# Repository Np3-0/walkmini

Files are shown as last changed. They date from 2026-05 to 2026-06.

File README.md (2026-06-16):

# Walk-Mini
A customizable, portable music player created for Hack Club: Fallout.

## About Walk-Mini
Music is one of the only genres that can connect people who believe in different topics, live in different areas, and who even speak different languages. However, it is becoming harder to listen to it, without shelling out 10 dollars a month, or buying a vinyl (which nobody will carry around). <br> People already carry around old IPods and other technology like this, so I wanted to make my own spin on it.

## Key Features
* Fully customizable theming
  - Users can print their own cases and choose between a wide range of themes for the firmware.
* Bluetooth, Headphone Jack, and Speaker support!
* 2.4 Inch TFT display with vibrant colors!
* Unlimited Song Storage!
  - Depends on SD size.
* And More!

## How to Use
1. Put in **4 AA Batteries**.
2. It should start up automatically!
   - I would recommend taking batteries out when not in use, in order to save power.
<br>
On the main page, there are six options (characterized with icons): Restart, Pause/Resume, Skip, Songs, Shuffle, and Settings.
<br>The settings page contains Customize, Bluetooth, and Contributions.

## How to Build
1. Buy all parts listed.
2. Print the case bottom, top, and battery cover (I would recommend either TPU or PLA).
3. Once the PCB arrives, solder all components onto it, following the PCB layout.
4. Connect a USB-C cable to the USB-header from your computer, and use the Arduino editor to flash the firmware onto the ESP.
5. Put the assembled PCB inside of the case, and enjoy!
6. Make sure you have songs loaded into the SD Card. 

## Photos
### **PCB**:<br> image of pcb in kicad
### **Zine:** <br> zine
### **CAD: (Link [here](https://cad.onshape.com/documents/891581ea64ec99eaf423b0d6/w/ed4d009452ec0fea7080dfa2/e/6ade851cf838900c5ee38ccd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))** <br> cad

##

## BOM
| Part Name | Description | Quantity | Unit Price | Total Price | URL | Running Total |
| --- | --- | --- | --- | --- | --- | --- |
| ESP32-WROOM-32E-N4 | MCU | 1 | $3.22 | $3.22 | [AliExpress](https://www.aliexpress.us/item/3256806057158706.html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) | $3.43
| CP2102-GMR | USB to UART | 1 | $0.80 | $0.80 | [AliBaba](https://www.alibaba.com/product-detail/New-and-Original-CP2102-GMR-Electronic_1601731751516.html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) | $4.28
| SD-6-B | SD Card Reader | 1 | $0.58[^1] | $0.58 | [Same Sky](https://www.sameskydevices.com/product/interconnect/connectors/memory-card-connectors/sd-card-connectors/sd-6-b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) | $4.90
| 1825910-6 | 6mm Button | 6[^2] | $0.057 | 1.14 | [AliExpress](https://www.aliexpress.us/item/3256805658758223.html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) | $5.26
| PCM5102APWR | Audio Jack Controller | 1 | $1.00 | $1.00 | [AliBaba](https://www.alibaba.com/product-detail/PCM5102APWR-IC-Chip-20-TSSOP-Brand_1600511085959.html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) | $6.33 
| MAX98357AETE+T | Speaker Controller | 1 | $0.10 | $0.10 | [AliBaba](https://www.alibaba.com/product-detail/New-and-Original-MAX98357AETE-T-Electronic_1601732000471.html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) | $6.44
| SJ-3523-SMT-TR | Headphone Jack | 1 | $0.88 | $0.88 | [DigiKey](https://www.digikey.com/en/products/detail/same-sky-formerly-cui-devices/SJ-3523-SMT-TR/281297) | $7.38
| AI-4328-P-C120D-R | Speaker | 1 | $16.92 | $16.92 | [DigiKey](https://www.digikey.com/en/products/detail/pui-audio-inc/ai-4328-p-c120d-r/1738481) | $25.42
| 2477 | Battery Holder | 1 | $1.87 | $1.87 | [Digikey](https://www.digikey.com/en/products/detail/keystone-electronics/2477/303822) | $27.41
| MCP1826S-3302E/AB | LDO | 1 | $0.66 | $0.66 | [AliBaba](https://www.alibaba.com/product-detail/Electronic-Circuit-Components-MCP1826S-3302E-AB_1601731375638.html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) | $28.11
| USB4085-GF-A | USB-C Connector | 1 | $0.04 | $0.04 | [AliBaba](https://www.alibaba.com/product-detail/Hainayu-BOM-capacitor-resistance-table-quotation_1601270438701.html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) | $28.15
| 1N5819 | Schottky Diode | 1 | $0.01 | $0.01 | [AliBaba](https://www.alibaba.com/product-detail/Through-hole-Schottky-Diodes-1N5817-1N5818_1601557699434.html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) | $28.16
| SSK02-FPH-254-A14 | Display 14 Pin Connector | 1 | $0.54 | $0.54 | [DigiKey](https://www.digikey.com/en/products/detail/same-sky-formerly-cui-devices/SSK02-FPH-254-A14/28772145) | $28.74
| ILI9341 | 2.4 Inch TFT Display | 1 | $5.16 | $5.16 | [AliExpress](https://www.aliexpress.us/item/3256803732365701.html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) | $34.24
| PCB | JLCPCB for project | 5 | $1.64 | $8.20 | [JLCPCB](https://jlcpcb.com/) | $42.98
| ABS07-32.768KHZ-T | 32.768 Khz Crsytal | 1 | $0.61 | $0.61 | [Digikey](https://www.digikey.com/en/products/detail/abracon-llc/ABS07-32-768KHZ-T/1236858) | $43.63
| MBA02040C3003FC100 | 300K Ohm Resistor | 1 | $0.66 | $0.66 | [Digikey](https://www.digikey.com/en/products/detail/vishay-beyschlag-draloric-bc-components/MBA02040C3003FC100/7350347) | $44.33
| MBA02040C1002FRP00 | 10K Ohm Resistor | 10 | $0.095 | $0.95 | [Digikey](https://www.digikey.com/en/products/detail/vishay-beyschlag-draloric-bc-components/MBA02040C1002FRP00/336349) | $45.34
| MBA02040Z0000ZCT00 | 0 Ohm Resistor | 2 | $0.14 | $0.28 | [Digikey](https://www.digikey.com/en/products/detail/vishay-beyschlag-draloric-bc-components/MBA02040Z0000ZCT00/5066485) | $45.64
| MBA02040C5104FC100 | 5M Ohm Resistor | 1 | $0.39 | $0.39 | [Digikey](https://www.digikey.com/en/products/detail/vishay-beyschlag-draloric-bc-components/MBA02040C5104FC100/5059352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) | $46.06
| MBA02040C4707JC100 | 470 Ohm Resistor | 2 | $0.11 | $0.22 | [Digikey](https://www.digikey.com/en/products/detail/vishay-beyschlag-draloric-bc-components/MBA02040C4700FRP00/333739) | $46.29
| MBA02040C5101FRP00 | 5.1K Ohm Resistor | 2 | $0.11 | $0.22 | [Digikey](https://www.digikey.com/en/products/detail/vishay-beyschlag-draloric-bc-components/MBA02040C5101FRP00/333758) | $46.52
| MBA02040C2209FCT00 | 22 Ohm Resistor | 2 | $0.21 | $0.42 | [Digikey](https://www.digikey.com/en/products/detail/vishay-beyschlag-draloric-bc-components/MBA02040C2209FCT00/5062426) | $46.97
| FK14X5R0J226MR020 | 22 µF Capacitor | 2 | $0.50 | $1.00 | [Digikey](https://www.digikey.com/en/products/detail/tdk/FK14X5R0J226MR020/2815215) | $48.04
| FK14X7R2A104KN020 | 0.1 µF Capacitor | 10 | $0.253 | $2.53 | [Digikey](https://www.digikey.com/en/products/detail/tdk/FK14X7R2A104KN020/2815243) | $50.74
| FG18C0G1H120JNT06 | 12pF Capacitor | 2 | $0.22 | $0.44 | [Digikey](https://www.digikey.com/en/products/detail/tdk/FG18C0G1H120JNT06/5802787) | $51.21
| FG18X7R1A225KRT06 | 2.2 µF Capacitor | 4 | $0.32 | $1.28 | [Digikey](https://www.digikey.com/en/products/detail/tdk/FG18X7R1A225KRT06/5802874) | $52.57
| FK18X5R0J105KN020 | 1 µF Capacitor | 2 | $0.28 | $0.56 | [Digikey](https://www.digikey.com/en/products/detail/tdk/FK18X5R0J105KN020/2815325) | $53.17
| FK18X5R1A475KR020 | 4.7 µF Capacitor | 1 | $0.34 | $0.34 | [Digikey](https://www.digikey.com/en/products/detail/tdk/FK18X5R1A475KR020/2815334) | $53.53
| ECE-A1EKA100I | 10 µF Polarized Capacitor | 5 | $0.26 | $1.30 | [Digikey](https://www.digikey.com/en/products/detail/panasonic-industry/ECE-A1EKA100I/2689086) | $54.92

**Enjoy!**
---
Made with love by Np3 (nate), 17, NJ

[^1]: Price is assumed for one SD-reader. For multiple, go [here:](https://www.alibaba.com/product-detail/Brand-New-Original-CONN-SD-CARD_1601485307544.html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)
[^2]: Button comes in package of 20.

# License
Shield: [][cc-by-nc-sa]

This work is licensed under a
[Creative Commons Attribution-NonCommercial-ShareAlike 4.0 International License][cc-by-nc-sa].

[][cc-by-nc-sa]

[cc-by-nc-sa]: http://creativecommons.org/licenses/by-nc-sa/4.0/
[cc-by-nc-sa-image]: https://licensebuttons.net/l/by-nc-sa/4.0/88x31.png
[cc-by-nc-sa-shield]: https://img.shields.io/badge/License-CC%20BY--NC--SA%204.0-lightgrey.svg

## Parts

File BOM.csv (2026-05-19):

Part Name | Description | Quantity | Unit Price | Total Price | URL | Running Total
ESP32-WROOM-32E-N4 | MCU | 1 | $3.22 | $3.22 | https://www.aliexpress.us/item/3256806057158706.html | $3.43
CP2102-GMR | USB to UART | 1 | $0.80 | $0.80 | https://www.alibaba.com/product-detail/New-and-Original-CP2102-GMR-Electronic_1601731751516.html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 | $4.28
SD-6-B | SD Card Reader | 1 | $0.58 | $0.58 | https://www.sameskydevices.com/product/interconnect/connectors/memory-card-connectors/sd-card-connectors/sd-6-b | $4.90
1825910-6 | 6mm Button | 6 | $0.06 | $0.34 | https://www.aliexpress.us/item/3256805658758223.html?curPageLogUid=a4N1OIlqDFoz | $5.26
PCM5102APWR | Audio Jack Controller | 1 | $1.00 | $1.00 | https://www.alibaba.com/product-detail/New-and-Original-MAX98357AETE-T-Electronic_1601732000471.html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 | $6.33
MAX98357AETE+T | Speaker Controller | 1 | $0.10 | $0.10 | https://www.alibaba.com/product-detail/New-and-Original-MAX98357AETE-T-Electronic_1601732000471.html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 | $6.44
SJ-3523-SMT-TR | Headphone Jack | 1 | $0.88 | $0.88 | https://www.digikey.com/en/products/detail/same-sky-formerly-cui-devices/SJ-3523-SMT-TR/281297 | $7.38
AI-4328-P-C120D-R | Speaker | 1 | $16.92 | $16.92 | https://www.digikey.com/en/products/detail/pui-audio-inc/ai-4328-p-c120d-r/1738481 | $25.42
2477 | Battery Holder | 1 | $1.87 | $1.87 | https://www.digikey.com/en/products/detail/keystone-electronics/2477/303822 | $27.41
MCP1826S-3302E/AB | LDO | 1 | $0.66 | $0.66 | https://www.alibaba.com/product-detail/Electronic-Circuit-Components-MCP1826S-3302E-AB_1601731375638.html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 | $28.11
USB4085-GF-A | USB-C Connector | 1 | $0.04 | $0.04 | https://www.alibaba.com/product-detail/Hainayu-BOM-capacitor-resistance-table-quotation_1601270438701.html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 | $28.15
1N5819 | Schottky Diode | 1 | $0.01 | $0.01 | https://www.alibaba.com/product-detail/Through-hole-Schottky-Diodes-1N5817-1N5818_1601557699434.html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 | $28.16
SSK02-FPH-254-A14 | Display 14 Pin Connector | 1 | $0.54 | $0.54 | https://www.digikey.com/en/products/detail/same-sky-formerly-cui-devices/SSK02-FPH-254-A14/28772145 | $28.74
ILI9341 | 2.4 Inch TFT Display | 1 | $5.16 | $5.16 | https://www.aliexpress.us/item/3256803732365701.html?curPageLogUid=W4D3fCRCIHOw | $34.24
PCB | JLCPCB for project | 5 | $1.64 | $8.20 | https://jlcpcb.com/ | $42.98
ABS07-32.768KHZ-T | 32.768 Khz Crsytal | 1 | $0.61 | $0.61 | https://www.digikey.com/en/products/detail/abracon-llc/ABS07-32-768KHZ-T/1236858 | $43.63
MBA02040C3003FC100 | 300K Ohm Resistor | 1 | $0.66 | $0.66 | https://www.digikey.com/en/products/detail/vishay-beyschlag-draloric-bc-components/MBA02040C3003FC100/7350347 | $44.33
MBA02040C1002FRP00 | 10K Ohm Resistor | 10 | $0.10 | $0.95 | https://www.digikey.com/en/products/detail/vishay-beyschlag-draloric-bc-components/MBA02040Z0000ZCT00/5066485 | $45.34
MBA02040Z0000ZCT00 | 0 Ohm Resistor | 2 | $0.14 | $0.28 | https://www.digikey.com/en/products/detail/vishay-beyschlag-draloric-bc-components/MBA02040Z0000ZCT00/5066485 | $45.64
MBA02040C5104FC100 | 5M Ohm Resistor | 1 | $0.39 | $0.39 | https://www.digikey.com/en/products/detail/vishay-beyschlag-draloric-bc-components/MBA02040C5104FC100/5059352 | $46.06
MBA02040C4707JC100 | 470 Ohm Resistor | 2 | $0.49 | $0.98 | https://www.digikey.com/en/products/detail/vishay-beyschlag-draloric-bc-components/MBA02040C4707JC100/5059320 | $47.10
MBA02040C5101FRP00 | 5.1K Ohm Resistor | 2 | $0.11 | $0.22 | https://www.digikey.com/en/products/detail/vishay-beyschlag-draloric-bc-components/MBA02040C5101FRP00/333758 | $47.33
MBA02040C2209FCT00 | 22 Ohm Resistor | 2 | $0.21 | $0.42 | https://www.digikey.com/en/products/detail/vishay-beyschlag-draloric-bc-components/MBA02040C2209FCT00/5062426 | $47.78
FK14X5R0J226MR020 | 22 µF Capacitor | 2 | $0.50 | $1.00 | https://www.digikey.com/en/products/detail/tdk/FK14X5R0J226MR020/2815215 | $48.85
FK14X7R2A104KN020 | 0.1 µF Capacitor | 10 | $0.25 | $2.53 | https://www.digikey.com/en/products/detail/tdk/FK14X7R2A104KN020/2815243 | $51.55
FG18C0G1H120JNT06 | 12pF Capacitor | 2 | $0.22 | $0.44 | https://www.digikey.com/en/products/detail/tdk/FG18C0G1H120JNT06/5802787 | $52.02
FG18X7R1A225KRT06 | 2.2 µF Capacitor | 4 | $0.32 | $1.28 | https://www.digikey.com/en/products/detail/tdk/FG18X7R1A225KRT06/5802874 | $53.38
FK18X5R0J105KN020 | 1 µF Capacitor | 2 | $0.28 | $0.56 | https://www.digikey.com/en/products/detail/tdk/FK18X5R0J105KN020/2815325 | $53.98
FK18X5R1A475KR020 | 4.7 µF Capacitor | 1 | $0.34 | $0.34 | https://www.digikey.com/en/products/detail/tdk/FK18X5R1A475KR020/2815334 | $54.34
ECE-A1EKA100I | 10 µF Polarized Capacitor | 5 | $0.26 | $1.30 | https://www.digikey.com/en/products/detail/panasonic-industry/ECE-A1EKA100I/2689086 | $55.73

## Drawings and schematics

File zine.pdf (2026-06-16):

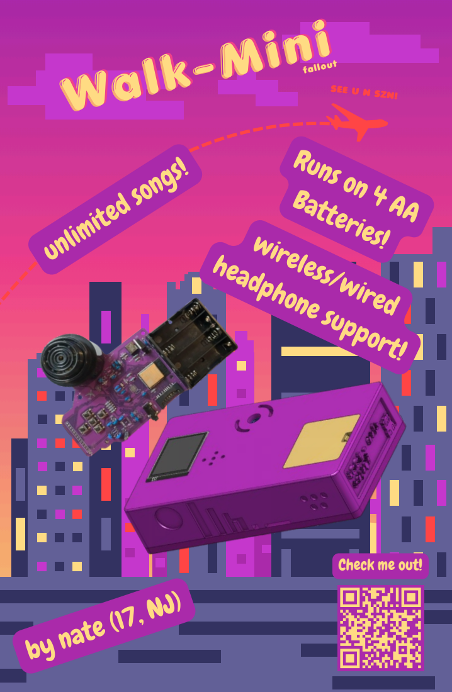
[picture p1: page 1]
Batteries! wireless/wired headphone support!; SE E U N SZN!; SE E U N SZN! SE E U N SZN!; unlimited songs!; Wal k -Mini; Wal k -Mini Wal k -Mini

fal lout fal lout

Runs on 4 AA

Check me out!

by nate (17, NJ)

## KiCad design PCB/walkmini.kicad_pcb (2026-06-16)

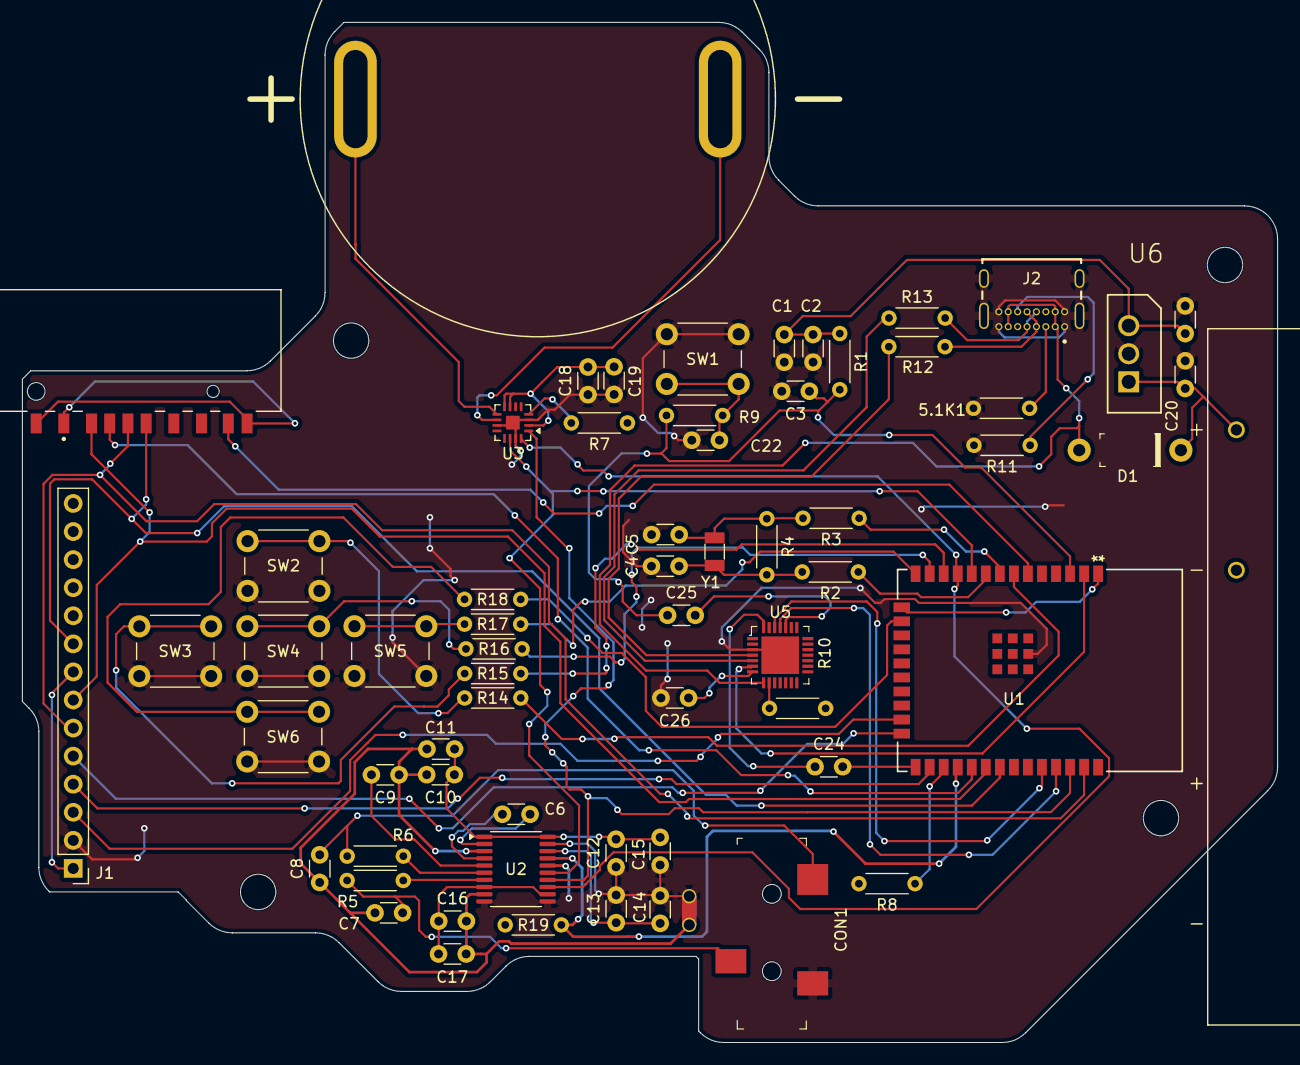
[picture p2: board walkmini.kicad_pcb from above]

Board: 2 copper layers, 113.6 x 92.3 mm, 64 parts (0 on the bottom side), 53 nets.

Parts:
5.1K1: 300K; R_Axial_DIN0204_L3.6mm_D1.6mm_P5.08mm_Horizontal
BT1: 6V; BAT_2477
C1: 22uF; C_Disc_D3.0mm_W1.6mm_P2.50mm
C2, C10, C12, C13, C16, C18, C22: 0.1uF; C_Disc_D3.0mm_W1.6mm_P2.50mm
C3, C24, C25: 100nF; C_Disc_D3.0mm_W1.6mm_P2.50mm
C4, C5: 12pF; C_Disc_D3.0mm_W1.6mm_P2.50mm
C6, C7, C8, C9: 2.2uF; C_Disc_D3.0mm_W1.6mm_P2.50mm
C11, C14, C15, C17, C19: 10uF; C_Disc_D3.0mm_W1.6mm_P2.50mm
C20, C21: 1 uF; C_Disc_D3.0mm_W1.6mm_P2.50mm
C26: 4.7uF; C_Disc_D3.0mm_W1.6mm_P2.50mm
CON1: SJ-3523-SMT-TR; Switch_Slide_11.6x4mm_SJ-3523-SMT
D1: 1N5819; DO-41
J1: Conn_01x14; PinHeader_1x14_P2.54mm_Vertical
J2: USB4085-GF-A_REVB; GCT_USB4085-GF-A_REVB
LS1: Speaker; XDCR_AI-4328-P-C120D-R
R1, R8, R9, R10, R14, R15, R16, R17, R18, R19: 10K; R_Axial_DIN0204_L3.6mm_D1.6mm_P5.08mm_Horizontal
R2, R3: 0 NC; R_Axial_DIN0204_L3.6mm_D1.6mm_P5.08mm_Horizontal
R4: 5; R_Axial_DIN0204_L3.6mm_D1.6mm_P5.08mm_Horizontal
R5, R6: 470; R_Axial_DIN0204_L3.6mm_D1.6mm_P5.08mm_Horizontal
R7: 300K; R_Axial_DIN0204_L3.6mm_D1.6mm_P5.08mm_Horizontal
R11: 5.1K; R_Axial_DIN0204_L3.6mm_D1.6mm_P5.08mm_Horizontal
R12, R13: 22; R_Axial_DIN0204_L3.6mm_D1.6mm_P5.08mm_Horizontal
SD_R1: CUI_SD-6-B
SW1, SW2, SW3, SW4, SW5, SW6: SW_Push; SW_PUSH_6mm
U1: ESP32-WROOM-32E-N4; ESP32­WROOM­32E_EXP
U2: PCM5102A; TSSOP-20_4.4x6.5mm_P0.65mm
U3: MAX98357A; TQFN-16-1EP_3x3mm_P0.5mm_EP1.23x1.23mm
U5: CP2102-GMR_NRND; VFQFN-28-1EP_5x5mm
U6: MCP1826S; TO254P482X1024X3124-3P
Y1: 32.768Khz; Crystal_SMD_3215-2Pin_3.2x1.5mm

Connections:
+3V3: C1.1, C2.1, C10.1, C11.1, C12.2, C15.1, C16.1, C17.1, C18.2, C19.2, C21.1, C26.1, J1.1, J1.8, R1.1, R7.1, R8.2, R10.2, R14.1, R15.1, R16.1, R17.1, R18.1, R19.1, SD_R1.P1, SD_R1.P8, SD_R1.P9, U1.2 (3V3), U1.7 (IO35), U1.12 (IO27), U1.13 (IO14), U1.14 (IO12), U1.16 (IO13), U2.1 (CPVDD), U2.8 (AVDD), U2.12 (SCK), U2.20 (DVDD), U3.2 (GAIN_SLOT), U3.7 (VDD), U3.8 (VDD), U5.6 (VDD), U5.7 (REGIN), U6.3 (VO)
GND: 5.1K1.1, C1.2, C2.2, C3.2, C4.1, C5.2, C12.1, C13.2, C14.2, C15.2, C18.1, C19.1, C20.2, C21.2, C22.1, C26.2, CON1.1 (S), J1.2, J2.A1 (GND), J2.A12 (GND__1), J2.B1 (GND__2), J2.B12 (GND__3), J2.S1 (SHELL), J2.S2 (SHELL__1), J2.S3 (SHELL__2), J2.S4 (SHELL__3), R11.2, SW1.2, SW2.1, SW3.1, SW4.1, SW5.1, SW6.1, U1.47 (GND), U2.10 (DEMP), U2.11 (FLT), U2.16 (FMT), U2.19 (DGND), U3.3 (GND), U3.11 (GND), U3.15 (GND), U3.17 (PAD), U5.3 (GND), U5.29 (GND_PAD), U6.2 (GND)
GNDA: C7.1, C8.1, C9.1, C10.2, C11.2, C16.2, C17.2, U2.3 (CPGND), U2.9 (AGND)
unnamed: BT1.P, C20.1, D1.K, U6.1 (VI)
unnamed: C4.2, R2.2, R4.2, Y1.2
unnamed: C5.1, R3.2, R4.1, Y1.1
unnamed: C22.2, R9.1, SW1.1
unnamed: C7.2, CON1.3 (R), R5.1
unnamed: C8.2, CON1.2 (T), R6.2
unnamed: J1.3, U1.23 (IO15)
unnamed: J1.4, U1.26 (IO4)
unnamed: J1.5, U1.24 (IO2)
unnamed: J1.6, SD_R1.P3, U1.37 (IO23)
unnamed: J1.7, SD_R1.P2, U1.30 (IO18)
unnamed: J1.9, SD_R1.P4, U1.31 (IO19)
unnamed: 5.1K1.2, J2.A5 (CC1)
unnamed: J2.B5 (CC2), R11.1
unnamed: J2.A7 (DN1), J2.B7 (DN2), R13.2
unnamed: J2.A6 (DP1), J2.B6 (DP2), R12.2
unnamed: D1.A, J2.A4 (VBUS), J2.A9 (VBUS__1), J2.B4 (VBUS__2), J2.B9 (VBUS__3), U5.8 (VBUS)
unnamed: R14.2, SW2.2
unnamed: R15.2, SW3.2
unnamed: R16.2, SW4.2
unnamed: R17.2, SW5.2
unnamed: R18.2, SW6.2
unnamed: SD_R1.P7, U1.6 (IO34)
unnamed: SD_R1.CD, U1.29 (IO5)
unnamed: C3.1, C25.1, R1.2, R9.2, U1.3 (EN)
unnamed: U1.1 (GND), U1.15 (GND)
unnamed: C24.2, U1.25 (IO0)
unnamed: R8.1, U1.27 (IO16)
unnamed: U1.36 (IO22), U2.14 (DIN), U3.1 (DIN)
unnamed: U1.10 (IO25), U2.15 (LRCK), U3.14 (LRCLK)
unnamed: U1.11 (IO26), U2.13 (BCK), U3.16 (BCLK)
unnamed: R3.1, U1.8 (IO32)
unnamed: R2.1, U1.9 (IO33)
unnamed: U1.34 (RXD0), U5.26 (TXD)
unnamed: U1.35 (TXD0), U5.25 (RXD)
unnamed: C6.1, U2.4 (CAPM)
unnamed: C6.2, U2.2 (CAPP)
unnamed: C13.1, C14.1, U2.18 (LDOO)
unnamed: R6.1, U2.6 (OUTL)
unnamed: R5.2, U2.7 (OUTR)
unnamed: C9.2, U2.5 (VNEG)
unnamed: R19.2, U1.28 (IO17), U2.17 (XSMT)
unnamed: LS1.N, U3.10 (OUTN)
unnamed: LS1.P, U3.9 (OUTP)
unnamed: R7.2, U3.4 (~SD_MODE)
unnamed: R12.1, U5.4 (D+)
unnamed: R13.1, U5.5 (D-)
unnamed: C24.1, U5.28 (DTR)
unnamed: R10.1, U5.9 (RST)
unnamed: C25.2, U5.24 (RTS)

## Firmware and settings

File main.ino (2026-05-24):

#include <Adafruit_GFX.h>
#include <Adafruit_ILI9341.h>
#include <Fonts/FreeSansBold12pt7b.h>

#define TFT_CS 30
#define TFT_DC 32

struct Color {
  int r;
  int g;
  int b;
};

// basic state controllers
int theme = 0;
int inApp = 0;
bool isPlaying = true;

// holds RGB for available themes
Color availableThemes[5][4] = {{{40, 40, 40}, {24, 24, 24}, {64, 64, 64}, {255, 255, 255}},
  {{248, 249, 250}, {173, 181, 189}, {222, 226, 230}, {0, 0, 0}},
  {{189, 224, 254}, {205, 180, 219}, {162, 210, 255}, {255, 255, 255}},
  {{58, 90, 64}, {52, 78, 65}, {88, 129, 87}, {218, 215, 205}},
  {{197, 55, 204}, {255, 69, 69}, {170, 42, 170}, {255, 219, 131}}
};

#define BG display.color565(availableThemes[theme][0].r, availableThemes[theme][0].g, availableThemes[theme][0].b)
#define ACCENT_ONE display.color565(availableThemes[theme][1].r, availableThemes[theme][1].g, availableThemes[theme][1].b)
#define ACCENT_TWO display.color565(availableThemes[theme][2].r, availableThemes[theme][2].g, availableThemes[theme][2].b)
#define HIGHLIGHT display.color565(availableThemes[theme][3].r, availableThemes[theme][3].g, availableThemes[theme][3].b)


Adafruit_ILI9341 display = Adafruit_ILI9341(TFT_CS, TFT_DC);

// menu states
int menuPos[2] = {0, 0};
int menuLimits[5][2] = {{0, 0}, {2, 1}, {0, 3}, {1, 3}, {0, 0}};
int mainMenuIconPos[6][2] = {{40, 100}, {130, 100}, {210, 100}, {40, 180}, {130, 180}, {210, 180}};
int settingsIconPos[4][2] = {{15, 15}, {24, 63}, {24, 112}, {24, 161}};
int customizeIconPos[7][2] = {{15, 15}, {24, 53}, {176, 53}, {24, 108}, {176, 108}, {24, 163}, {176, 163}};
int contributionIconPos[2] = {15, 15};

void setup() {
  Serial.begin(9600);
  delay(1000);
  for (int i = 3; i < 8; i++) {
    pinMode(i, INPUT_PULLUP);
  }

  display.begin();
  delay(500);
  display.fillScreen(BG);
  display.setFont(&FreeSansBold12pt7b);
  display.setRotation(1);

  showStartMenu();

  while (!isButtonPressed());
  delay(50);

  inApp = 1;
  showMainMenu();
}

void loop() {
  if (isButtonPressed()) {
    int oldPos = getMenuIndex();
    int buttonClicked = determineButtonPressed();
    if (buttonClicked == 3) {
      showCorrectMenu();
      delay(150);
      return;
    }
    moveMenuPos(buttonClicked);
    int newPos = getMenuIndex(); // recall so it updates to the new pos

    // swaps which item is selected
    drawIcon(oldPos, false);
    drawIcon(newPos, true);

    while (!isButtonPressed());
    delay(50);
  }
  delay(100);
}

void showStartMenu() {
  clear();
  display.setCursor(0, 50);
  display.setTextColor(HIGHLIGHT);
  display.setTextSize(2);
  display.println("Walk-mini");
  display.setTextSize(1);
  display.setCursor(0, 150);
  display.println("Press button to begin");
  delay(100);
}

void showMainMenu() {
  clear();
  resetPos();

  display.fillRect(0, 0, 320, 90, ACCENT_ONE);
  display.setCursor(5, 25);
  display.setTextColor(HIGHLIGHT);
  display.setTextSize(1);
  display.println("Song Name");
  display.setCursor(5, 50);
  display.println("Artist");

  display.setCursor(135, 55);
  display.println("0:00");
  display.fillRect(250, 15, 45, 45, HIGHLIGHT);

  // progress bar
  display.fillRect(60, 80, 200, 5, HIGHLIGHT);
  display.fillCircle(160, 82, 8, HIGHLIGHT);

  for (int i = 0; i < 6; i++) {
    drawIcon(i, i == 0);
  }
}

void showSettings() {
  clear();
  resetPos();

  display.setTextSize(2);
  display.setCursor(80, 45);
  display.setTextColor(HIGHLIGHT);
  display.println("Settings");
  display.setTextSize(1);

  for (int i = 0; i < 4; i++) {
    drawIcon(i, i == 0);
  }
}

void showCustomizeMenu() {
  clear();
  resetPos();

  display.setTextSize(1);
  display.setCursor(100, 35);
  display.setTextColor(HIGHLIGHT);
  display.println("Customize");
  for (int i = 0; i < 7; i++) {
    drawIcon(i, i == 0);
  }
}

void showContributionsMenu() {
  clear();
  resetPos();

  drawIcon(0, 0 == 0);
  display.setCursor(15, 60);
  display.setTextColor(HIGHLIGHT);
  display.println("WalkMini: by nate/np3");
  display.setCursor(15, 100);
  display.println("HackClub: For Fallout");
  display.setCursor(15, 140);
  display.println("Mom & Dad: Support!");
  display.setCursor(15, 180);
  display.println("JLCPCB: PCB");
  display.setCursor(15, 220);
  display.println("You: For using Walkmini!");
}

void showBluetoothMenu() {
  clear();
  resetPos();

  display.setTextSize(2);
  display.setCursor(80, 45);
  display.setTextColor(HIGHLIGHT);
  display.println("Bluetooth");
  display.setTextSize(1);
  display.setCursor(15, 90);
  display.println("Devices Found:");
  
  // call for all bluetooth devices (await?), then use it for length of list
  int devicesFound = 2;
  for (int i = 0; i < devicesFound; i++) {
    display.fillRoundRect(15, 110 + (i*20), 272, 42, 3, ACCENT_TWO);
  }
}

// takes current position of the user and completes action
void showCorrectMenu() {
  if (inApp == 1 ) {
    switch (getMenuIndex()) {
      case 0:
        Serial.println("Restart");
        break;
      case 1:
        Serial.println(isPlaying ? "Pause" : "Resume");
        isPlaying = !isPlaying;
        drawIcon(getMenuIndex(), getMenuIndex()); // recall to change state
        break;
      case 2:
        Serial.println("Skip");
        break;
      case 3:
        Serial.println("Songs");
        break;
      case 4:
        Serial.println("Shuffle");
        break;
      case 5:
        Serial.println("Settings");
        inApp = 2;
        showSettings();
        break;
    }
  } else if (inApp == 2) {
    switch (getMenuIndex()) {
      case 0:
        inApp = 1;
        showMainMenu();
        break;
      case 1:
        inApp = 3;
        showCustomizeMenu();
        break;
      case 2:
        Serial.println("Bluetooth");
        break;
      case 3:
        inApp = 4;
        showContributionsMenu();
        break;
    }
  } else if (inApp == 3) {
    int ind = getMenuIndex();
    if (ind == 0) {
      inApp = 2;
      showSettings();
    } else if (ind == 6) {
      //add submit code
      inApp = 1;
      showMainMenu();
    } else {
      theme = ind - 1;
      showCustomizeMenu();
    }
  } else if (inApp == 4){ 
    if (getMenuIndex() == 0) {
        inApp = 2;
        showSettings();
    }
  } else if (inApp == 5) {
    if (getMenuIndex() == 0) {
      inApp = 2;
      showSettings();
    }
    // a case will have to be refresh bluetooth. all others will connect to the selected device.
  }
}



void clear() {
  display.fillScreen(BG);
}

void resetPos() {
  menuPos[0] = 0;
  menuPos[1] = 0;
}

int getMenuIndex() {
  if (inApp == 1) {
    return menuPos[1] * 3 + menuPos[0];
  } else if (inApp == 2) {
    return menuPos[1];
  } else if (inApp == 3) {
    if (menuPos[1] == 0) return 0;
    return menuPos[1] * 2 + menuPos[0] - 1;
  } else if (inApp == 4) {
    return 0;  
  }

  return 0;
}

bool isButtonPressed() {
  for (int i = 3; i < 8; i++) {
    if (digitalRead(i) == LOW) return true;
  }
  return false;
}

int determineButtonPressed() {
  for (int i = 3; i < 8; i++) {
    if (digitalRead(i) == LOW) return i;
  }
}

void moveMenuPos(int button) {
  if (inApp == 0)
    return;

  // moves menu pos, action button not programmed.
  switch (button) {
    case 3:
      break;
    case 4:
      menuPos[0]++;
      break;
    case 5:
      menuPos[0]--;
      break;
    case 6:
      menuPos[1]++;
      break;
    case 7:
      menuPos[1]--;
      break;
  }

  // swapping to other side if going over limits
  if (menuPos[0] < 0) {
    menuPos[0] = menuLimits[inApp][0];
  } else if (menuPos[0] > menuLimits[inApp][0]) {
    menuPos[0] = 0;
  } else if (menuPos[1] < 0) {
    menuPos[1] = menuLimits[inApp][1];
  } else if (menuPos[1] > menuLimits[inApp][1]) {
    menuPos[1] = 0;
  } if (inApp == 3 && menuPos[1] == 0) {
    menuPos[1] == 0;
  }
}

void redrawIcons(int prevPos[2], int curPos[2]) {
  display.fillRoundRect(prevPos[0], prevPos[1], 55, 55, 3, ACCENT_TWO);
  display.fillRoundRect(curPos[0], curPos[1], 55, 55, 3, HIGHLIGHT);
}

void drawIcon(int index, bool isSelected) {
  int pos[2] = {0, 0};
  uint16_t bg = isSelected ? HIGHLIGHT : ACCENT_TWO;
  uint16_t fg = isSelected ? ACCENT_TWO : HIGHLIGHT;
  if (inApp == 1) {
    pos[0] = mainMenuIconPos[index][0];
    pos[1] = mainMenuIconPos[index][1];
    display.fillRoundRect(pos[0], pos[1], 55, 55, 3, bg);

    switch (index) {
      case 0: // restart
        display.fillTriangle(pos[0] + 42, pos[1] + 45, pos[0] + 42, pos[1] + 10, pos[0] + 24, pos[1] + 27, fg);
        display.fillTriangle(pos[0] + 24, pos[1] + 45, pos[0] + 24, pos[1] + 10, pos[0] + 6, pos[1] + 27, fg);
        break;
      case 1: // pause + resume
        if (isPlaying) {
          display.fillTriangle(pos[0] + 8, pos[1] + 9, pos[0] + 8, pos[1] + 46, pos[0] + 46, pos[1] + 27, fg);
        } else {
          display.fillRect(pos[0] + 8, pos[1] + 9, 13, 37, fg);
          display.fillRect(pos[0] + 32, pos[1] + 9, 13, 37, fg);
        }
        break;
      case 2: // skip
        display.fillTriangle(pos[0] + 10, pos[1] + 45, pos[0] + 10, pos[1] + 10, pos[0] + 27, pos[1] + 27, fg);
        display.fillTriangle(pos[0] + 27, pos[1] + 45, pos[0] + 27, pos[1] + 10, pos[0] + 45, pos[1] + 27, fg);
        break;
      case 3: // songs
        display.fillRect(pos[0] + 6, pos[1] + 15, 15, 25, fg);
        display.fillTriangle(pos[0] + 45, pos[1] + 5, pos[0] + 45, pos[1] + 50, pos[0] - 10, pos[1] + 25, fg);
        display.fillRoundRect(40, 180, 6, 55, 3, bg); // hides triangle part that goes off button
        display.fillRect(0, 150, 40, 90, BG);
        break;
      case 4: // shuffle
        display.fillRect(pos[0] + 10, pos[1] + 15, 30, 5, fg);
        display.fillTriangle(pos[0] + 40, pos[1] + 8, pos[0] + 40, pos[1] + 27, pos[0] + 50, pos[1] + 17, fg);
        display.fillRect(pos[0] + 15, pos[1] + 40, 30, 5, fg);
        display.fillTriangle(pos[0] + 15, pos[1] + 33, pos[0] + 15, pos[1] + 52, pos[0] + 5, pos[1] + 40, fg);
        break;
      case 5: // settings
        display.fillRect(pos[0] + 10, pos[1] + 15, 35, 5, fg);
        display.fillCircle(pos[0] + 32, pos[1] + 17, 5, fg);
        display.fillRect(pos[0] + 10, pos[1] + 28, 35, 5, fg);
        display.fillCircle(pos[0] + 17, pos[1] + 30, 5, fg);
        display.fillRect(pos[0] + 10, pos[1] + 40, 35, 5, fg);
        display.fillCircle(pos[0] + 32, pos[1] + 42, 5, fg);
    }
  } else if (inApp == 2) {
    pos[0] = settingsIconPos[index][0];
    pos[1] = settingsIconPos[index][1];

    switch (index) {
      case 0:
        display.fillRoundRect(10, 10, 30, 30, 3, bg);
        display.fillTriangle(35, 15, 35, 35, 15, 25, fg);
        break;
      case 1:
        display.fillRoundRect(pos[0], pos[1], 272, 42, 3, bg);
        display.setTextColor(fg);
        display.setCursor(32, 90);
        display.println("Customize");
        break;
      case 2:
        display.fillRoundRect(pos[0], pos[1], 272, 42, 3, bg);
        display.setTextColor(fg);
        display.setCursor(32, 140);
        display.println("Bluetooth");
        break;
      case 3:
        display.fillRoundRect(pos[0], pos[1], 272, 42, 3, bg);
        display.setTextColor(fg);
        display.setCursor(32, 190);
        display.println("Contributions");
        break;
    }
  } else if (inApp == 3) {
    pos[0] = customizeIconPos[index][0];
    pos[1] = customizeIconPos[index][1];

    switch (index) {
      case 0:
        display.fillRoundRect(10, 10, 30, 30, 3, bg);
        display.fillTriangle(35, 15, 35, 35, 15, 25, fg);
        break;
      case 1:
        display.fillRoundRect(pos[0], pos[1], 120, 45, 3, bg);
        display.fillRoundRect(pos[0] + 15, pos[1] + 15, 15, 15, 3, display.color565(availableThemes[0][0].r, availableThemes[0][0].g, availableThemes[0][0].b));
        display.fillRoundRect(pos[0] + 40, pos[1] + 15, 15, 15, 3, display.color565(availableThemes[0][1].r, availableThemes[0][1].g, availableThemes[0][1].b));
        display.fillRoundRect(pos[0] + 65, pos[1] + 15, 15, 15, 3, display.color565(availableThemes[0][2].r, availableThemes[0][2].g, availableThemes[0][2].b));
        display.fillRoundRect(pos[0] + 90, pos[1] + 15, 15, 15, 3, display.color565(availableThemes[0][3].r, availableThemes[0][3].g, availableThemes[0][3].b));
        break;
      case 2:
        display.fillRoundRect(pos[0], pos[1], 120, 45, 3, bg);
        display.fillRoundRect(pos[0] + 15, pos[1] + 15, 15, 15, 3, display.color565(availableThemes[1][0].r, availableThemes[1][0].g, availableThemes[1][0].b));
        display.fillRoundRect(pos[0] + 40, pos[1] + 15, 15, 15, 3, display.color565(availableThemes[1][1].r, availableThemes[1][1].g, availableThemes[1][1].b));
        display.fillRoundRect(pos[0] + 65, pos[1] + 15, 15, 15, 3, display.color565(availableThemes[1][2].r, availableThemes[1][2].g, availableThemes[1][2].b));
        display.fillRoundRect(pos[0] + 90, pos[1] + 15, 15, 15, 3, display.color565(availableThemes[1][3].r, availableThemes[1][3].g, availableThemes[1][3].b));
        break;
      case 3:
        display.fillRoundRect(pos[0], pos[1], 120, 45, 3, bg);
        display.fillRoundRect(pos[0] + 15, pos[1] + 15, 15, 15, 3, display.color565(availableThemes[2][0].r, availableThemes[2][0].g, availableThemes[2][0].b));
        display.fillRoundRect(pos[0] + 40, pos[1] + 15, 15, 15, 3, display.color565(availableThemes[2][1].r, availableThemes[2][1].g, availableThemes[2][1].b));
        display.fillRoundRect(pos[0] + 65, pos[1] + 15, 15, 15, 3, display.color565(availableThemes[2][2].r, availableThemes[2][2].g, availableThemes[2][2].b));
        display.fillRoundRect(pos[0] + 90, pos[1] + 15, 15, 15, 3, display.color565(availableThemes[2][3].r, availableThemes[2][3].g, availableThemes[2][3].b));
        break;
      case 4:
        display.fillRoundRect(pos[0], pos[1], 120, 45, 3, bg);
        display.fillRoundRect(pos[0] + 15, pos[1] + 15, 15, 15, 3, display.color565(availableThemes[3][0].r, availableThemes[3][0].g, availableThemes[3][0].b));
        display.fillRoundRect(pos[0] + 40, pos[1] + 15, 15, 15, 3, display.color565(availableThemes[3][1].r, availableThemes[3][1].g, availableThemes[3][1].b));
        display.fillRoundRect(pos[0] + 65, pos[1] + 15, 15, 15, 3, display.color565(availableThemes[3][2].r, availableThemes[3][2].g, availableThemes[3][2].b));
        display.fillRoundRect(pos[0] + 90, pos[1] + 15, 15, 15, 3, display.color565(availableThemes[3][3].r, availableThemes[3][3].g, availableThemes[3][3].b));
        break;
      case 5:
        display.fillRoundRect(pos[0], pos[1], 120, 45, 3, bg);
        display.fillRoundRect(pos[0] + 15, pos[1] + 15, 15, 15, 3, display.color565(availableThemes[4][0].r, availableThemes[4][0].g, availableThemes[4][0].b));
        display.fillRoundRect(pos[0] + 40, pos[1] + 15, 15, 15, 3, display.color565(availableThemes[4][1].r, availableThemes[4][1].g, availableThemes[4][1].b));
        display.fillRoundRect(pos[0] + 65, pos[1] + 15, 15, 15, 3, display.color565(availableThemes[4][2].r, availableThemes[4][2].g, availableThemes[4][2].b));
        display.fillRoundRect(pos[0] + 90, pos[1] + 15, 15, 15, 3, display.color565(availableThemes[4][3].r, availableThemes[4][3].g, availableThemes[4][3].b));
        break;
      case 6:
        display.fillRoundRect(pos[0], pos[1], 120, 45, 3, bg);
        display.setCursor(pos[0] + 17, pos[1] + 30);
        display.setTextSize(1);
        display.setTextColor(fg);
        display.println("Submit!");
        break;
    }
  } else if (inApp == 4) {
    pos[0] = customizeIconPos[index][0];
    pos[1] = customizeIconPos[index][1];

    display.fillRoundRect(10, 10, 30, 30, 3, bg);
    display.fillTriangle(35, 15, 35, 35, 15, 25, fg);
  }
}

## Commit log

2026-05-12 added to BOM
2026-05-12 BOM done
2026-05-16 upload BOM
    [BOM.csv]
2026-05-16 update readme BOM
2026-05-16 update BOM
    [BOM.csv]
2026-05-19 update BOM again
    Updated BOM.csv to reflect new part names and prices.
    [BOM.csv]
2026-05-19 added links
    [BOM.csv]
2026-05-19 fix BOM
    Updated component list with new parts and prices.
2026-05-19 fixing bom yet again
    [BOM.csv]
2026-05-24 add gerbers
2026-05-24 added pcb photo
2026-05-31 update BOM prices
2026-05-31 changed gerbers
2026-06-01 updating gerbers
2026-06-16 added CAD
2026-06-16 fixed cad
2026-06-16 added other pcb files
    [walkmini.kicad_pcb, walkmini.kicad_sch]
